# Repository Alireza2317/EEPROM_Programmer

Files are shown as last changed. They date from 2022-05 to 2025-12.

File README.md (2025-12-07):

# Arduino EEPROM Programmer (28C16)





A custom PCB shield and Arduino firmware designed to program **28C16 Parallel EEPROMs**.

This tool is essential for projects like the **Ben Eater 8-bit computer**, allowing you to burn microcode or 7-segment display logic into non-volatile memory without manually toggling dip switches.

## 🔌 Hardware Design (KiCad)
The `gerbers/` and root directory contain the full design files for a custom PCB that fits on top of an Arduino (or connects via headers).

* **Chip Support:** 28C16 (2K x 8-bit Parallel EEPROM).
* **Design Tool:** KiCad (Schematic & PCB files included).
* **Status:** Production-ready Gerber files are available in the `gerbers` folder.

### 📸 PCB Preview
<p align="center">
  PCB 3D Render
</p>

## 💻 Firmware (Arduino)
The C++ code in `arduino_programmer/` handles the write cycle timing and address management.

### Key Features
* **Write Cycle Control:** Manages the Write Enable (WE) and Chip Enable (CE) pulses required by the 28C16 datasheet.
* **7-Segment Decoding:** By default, the code includes a lookup table to program the EEPROM with hexadecimal digits (0-9) for a common-cathode 7-segment display.
* **Customizable:** You can modify the `data` array to burn any microcode instruction set.

## 🚀 Getting Started

### 1. Fabrication / Wiring
You can either:
* **Order the PCB:** upload the zip gerber files to a PCB manufacturer (JLCPCB, PCBWay, etc.).
* **Breadboard it:** Follow the pinout defined in the `arduino_programmer.ino` file to wire the EEPROM directly to the Arduino digital pins.

### 2. Flashing
1.  Open `arduino_programmer/arduino_programmer.ino` in the Arduino IDE.
2.  Connect your Arduino.
3.  **Verify the pin definitions** at the top of the file match your wiring.
4.  Upload the sketch.
5.  Open the **Serial Monitor** (57600 baud) to see the programming status.

## ⚠️ Important Notes

* **Timing:** The 28C16 requires a specific write pulse width (usually < 1ms). The code handles this, but check your specific datasheet if using a different variant (e.g., 28C64).

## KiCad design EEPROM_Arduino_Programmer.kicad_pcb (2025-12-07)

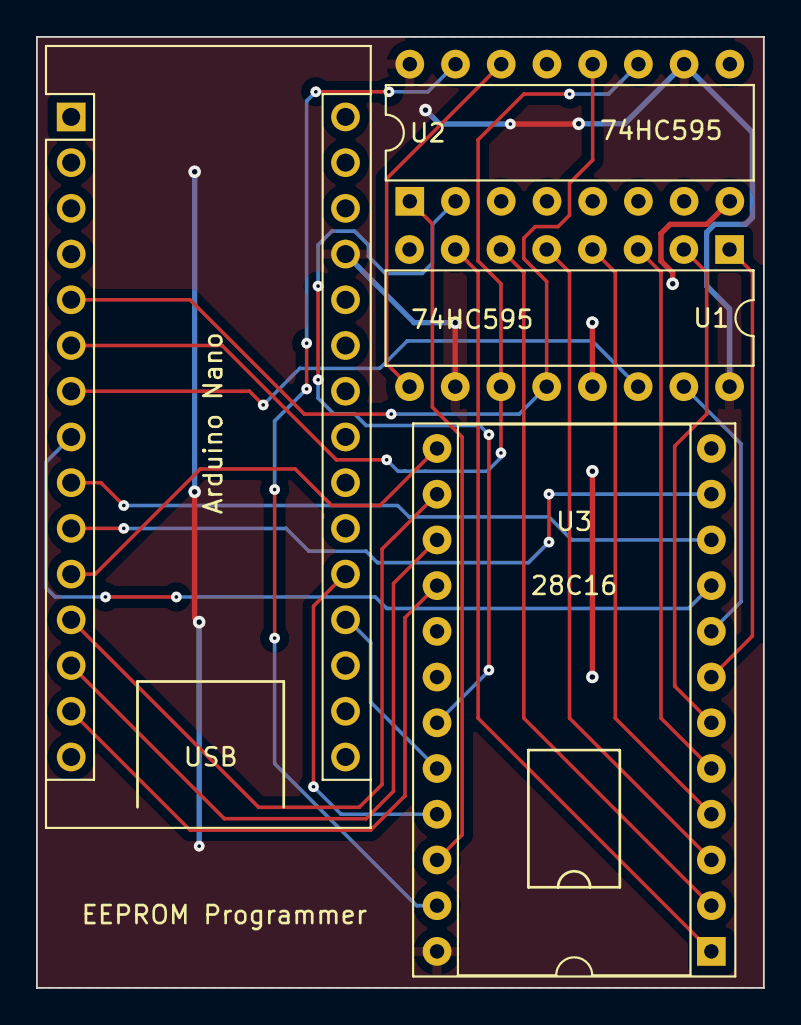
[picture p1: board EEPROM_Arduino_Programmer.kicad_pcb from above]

Board: 2 copper layers, 40.4 x 52.8 mm, 4 parts (0 on the bottom side), 26 nets.

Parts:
Arduino Nano: Arduino_Nano_v2.x; Arduino_Nano
U1, U2: 74HC595; DIP-16_W7.62mm
U3: 28C16_EEPROM; DIP-24_W15.24mm_Socket

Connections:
/A0: U1.15 (QA), U3.8 (A0)
/A1: U1.1 (QB), U3.7 (A1)
/A2: U1.2 (QC), U3.6 (A2)
/A3: U1.3 (QD), U3.5 (A3)
/A4: U1.4 (QE), U3.4 (A4)
/A5: U1.5 (QF), U3.3 (A5)
/A6: U1.6 (QG), U3.2 (A6)
/A7: U1.7 (QH), U3.1 (A7)
/A8: U2.15 (QA), U3.23 (A8)
/A9: U2.1 (QB), U3.22 (A9)
/A10: U2.2 (QC), U3.19 (A10)
/D0: Arduino Nano.8 (D5), U3.9 (I/O0)
/D1: Arduino Nano.9 (D6), U3.10 (I/O1)
/D2: Arduino Nano.10 (D7), U3.11 (I/O2)
/D3: Arduino Nano.11 (D8), U3.13 (I/O3)
/D4: Arduino Nano.12 (D9), U3.14 (I/O4)
/D5: Arduino Nano.13 (D10), U3.15 (I/O5)
/D6: Arduino Nano.14 (D11), U3.16 (I/O6)
/clk: Arduino Nano.5 (D2), U1.12 (RCLK), U2.12 (RCLK)
/data: Arduino Nano.7 (D4), U1.14 (SER)
/latch: Arduino Nano.6 (D3), U1.11 (SRCLK), U2.11 (SRCLK)
/~OE: Arduino Nano.19 (A0), U3.20 (~OE)
/~WE: Arduino Nano.20 (A1), U3.21 (~WE)
GND: Arduino Nano.4 (GND), Arduino Nano.29 (GND), U1.8 (GND), U1.13 (~OE), U2.8 (GND), U2.13 (~OE), U3.12 (GND), U3.18 (~CE)
unnamed: U1.9 (QH'), U2.14 (SER)
VCC: Arduino Nano.27 (+5V), U1.10 (~SRCLR), U1.16 (VCC), U2.10 (~SRCLR), U2.16 (VCC), U3.24 (VCC)

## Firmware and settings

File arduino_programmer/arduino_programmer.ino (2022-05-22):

// parallel EEPROM Programmer
// 28c16 IC
// written by: github.com/alireza2317
// inspired by Ben Eater


// using 2 shift registers (74HC595) we are gonna put the address on the outputs of them
// 8 bits of data (I/O) can be covered by other arduino pins
// also ~OE and ~WE can be connected to the arduino directly

// shift register pins
#define SHIFT_CLK 2
#define SHIFT_LATCH 3
#define SHIFT_DATA 4


// EEPROM pins
#define OE A0 // active low
#define WE A1 // active low

#define D0 5
#define D1 6
#define D2 7
#define D3 8
#define D4 9
#define D5 10
#define D6 11
#define D7 12


#define NUMBER_OF_ROWS_OF_EEPROM 2048


const byte data_pins[8] = {D0, D1, D2, D3, D4, D5, D6, D7};
 
void set_address(const unsigned int address) {
	// 8 bits at a time
	// 3 MS bits of the address
	shiftOut(SHIFT_DATA, SHIFT_CLK, LSBFIRST, address >> 8);
	// 8 LS remaining bits by default 
	shiftOut(SHIFT_DATA, SHIFT_CLK, LSBFIRST, address);
}

byte read_EEPROM(const unsigned int address) {
	set_address(address);
	
	// enabling the output of the EEPROM
	digitalWrite(OE, LOW);
	
	// setting the data pins as INPUT, because data will be read from them
	for (byte i=0; i<8; i++) {
		pinMode(data_pins[i], INPUT);
	}

	byte data = 0;
	for (byte i=7; i>=0; i--) {
		data = (data << 1) + digitalRead(data_pins[i]);
	}

	// disable the output enable pin
	digitalWrite(OE, HIGH);

	return data;
}

void show_EEPROM_content() {
	for (unsigned int base=0; base<NUMBER_OF_ROWS_OF_EEPROM; base+=16) {
		byte data[16];
		for (byte offset=0; offset<16; offset++) {
			data[offset] = read_EEPROM(base + offset);
		}
		
		char buffer[90];
		sprintf(
			buffer,
			"%03x: %02x %02x %02x %02x %02x %02x %02x %02x   %02x %02x %02x %02x %02x %02x %02x %02x", 
			base, 
			data[0], data[1], data[2], data[3], data[4], data[5], data[6], data[7],
			data[8], data[9], data[10], data[11], data[12], data[13], data[14], data[15]
		);

		Serial.println("     00 01 02 03 04 05 06 07   08 09 10 11 12 13 14 15");
		Serial.println(buffer);
	}
}

void write_EEPROM(const unsigned int address, byte data) {
	// disabling the output enable, because we want to write data to the chip
	digitalWrite(OE, HIGH);

	// setting the data pins as OUTPUT, because data will be sent to them
	for (byte i=0; i<8; i++) {
		pinMode(data_pins[i], OUTPUT);
	}

	for (byte i=0; i<8; i++) {
		digitalWrite(data_pins[i], data & 1);
		// shifting the data to right, so each time we can get the LSB by & 1
		data >>= 1;
	}
	digitalWrite(WE, HIGH);
	digitalWrite(WE, LOW);
	delayMicroseconds(1);
	digitalWrite(WE, HIGH);
	delay(15);
}

void erase_EEPROM() {
	for (unsigned int address=0; address<NUMBER_OF_ROWS_OF_EEPROM; address++) {
		write_EEPROM(address, 0xff);
	}
}


void setup() {
	// setting pin modes
	pinMode(SHIFT_CLK, OUTPUT);
	pinMode(SHIFT_LATCH, OUTPUT);
	pinMode(SHIFT_DATA, OUTPUT);
	pinMode(OE, OUTPUT);
	
	// the order of these two lines is correct as is
	// because if the pin is set to OUTPUT before setting it HIGH
	// it may go LOW and may accidentally write something to the chip
	digitalWrite(WE, HIGH);
	pinMode(WE, OUTPUT);

	Serial.begin(57600);

	// seven segment display(common cathode) data to decode it properly
	byte digits[10] = {0x7e, 0x30, 0x6d, 0x79, 0x33, 0x5b, 0x5f, 0x70, 0x7f, 0x7b};

	// seven segment display(common anode) data to decode it properly
	//byte digits[10] = {0x81, 0xcf, 0x92, 0x86, 0xcc, 0xa4, 0xa0, 0x8f, 0x80, 0x84};

	for (byte value=0; value<10; value++) {
		write_EEPROM(value, digits[value]);
	}

}

void loop() {
	// nothing
}

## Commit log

2022-05-22 created schematic & pcb in kicad and arduino code arduino code programs the chip for seven segment displays by default
    [EEPROM_Arduino_Programmer-B_Cu.gbr, EEPROM_Arduino_Programmer-B_Mask.gbr, EEPROM_Arduino_Programmer-B_Paste.gbr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]
2022-05-22 updated arduino code
2025-12-07 updated kicad version from 7 to 9!
    [EEPROM_Arduino_Programmer.kicad_pcb, EEPROM_Arduino_Programmer.kicad_sch]
2025-12-07 updated gerber files
    [EEPROM_Arduino_Programmer-B_Cu.gbr, EEPROM_Arduino_Programmer-B_Mask.gbr, EEPROM_Arduino_Programmer-B_Paste.gbr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]
2025-12-07 update pcb
    [EEPROM_Arduino_Programmer.kicad_pcb]

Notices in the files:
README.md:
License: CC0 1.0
